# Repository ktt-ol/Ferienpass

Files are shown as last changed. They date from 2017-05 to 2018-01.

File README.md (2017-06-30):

# Ferienpass

## Submodules
We use the [kicad-ESP8266][kicadESP8266Lib] Libary form [jdunmire][ESP8266LibAuthor].

To clone the whole Repository including the submodules simpy use the `--recusive` Option or run the Commands `git submodule init && git submodule update` inside this repository adter cloning.

[kicadESP8266Lib]: https://github.com/jdunmire/kicad-ESP8266
[ESP8266LibAuthor]: https://github.com/jdunmire

## Arduino Library
Install the following librarys via the Arduino IDE:
- Adafruit BME280 Library
- Adafruit GFX LIbrary
- Adafruit NeoPixel
- Adafruit Unified Sensor
- ACROBOTIC SSD1306

Modify three lib-files (first two for I2C):
- Adafruit_BME280.h: Line 32: Change `BME280_ADDRESS` from `0x77` to `0x76`
- Adafruit_BME280.cpp: Line 50: Change `Wire.begin();` to `Wire.begin(5, 4); // Pin D1, D2 of ESP`
- Adafruit_SSD1306.h: Line 73/74: use line 73 `#define SSD1306_128_64`  instead of line 74 `#define SSD1306_128_32`

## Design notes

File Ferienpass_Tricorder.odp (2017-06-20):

## Ferienpass

Multifunktionssensor bauen

## Vorstellungsrunde

## Spaceführung

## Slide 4

Löten lernen

## Löten lernen

- Lötkolben und Lötzinn
- Fachbegriffe
- Bauteile
  - Typen
  - Hinweise
- Richtig löten

## Lötkolben und Lötzinn

- Der Lötkolben wird sehr heiß (ca. 200°C)
- Das Lötzinn besteht aus Flussmittel, Zinn und Blei
- Nach dem Löten unbedingt die Hände waschen, da das Lötzinn gesundheitsschädlich ist!

## Fachbegriffe: U = R × I

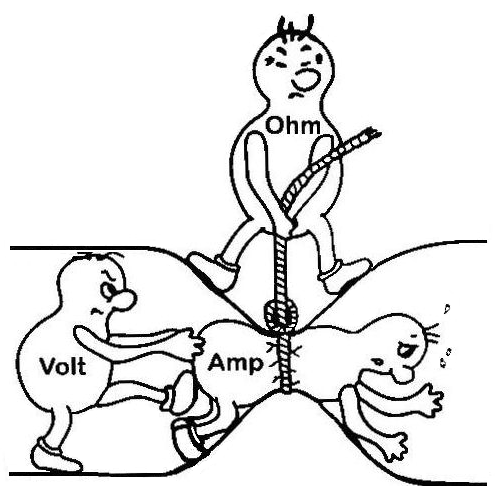
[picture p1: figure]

## Bauteile - Widerstand

- Zeichen: R
- Polung: Keine
- Einheit: Ohm
- Anhand von Farbringen erkennbar
- Beispiel

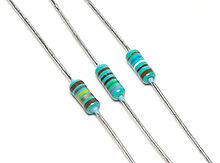
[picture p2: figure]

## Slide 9

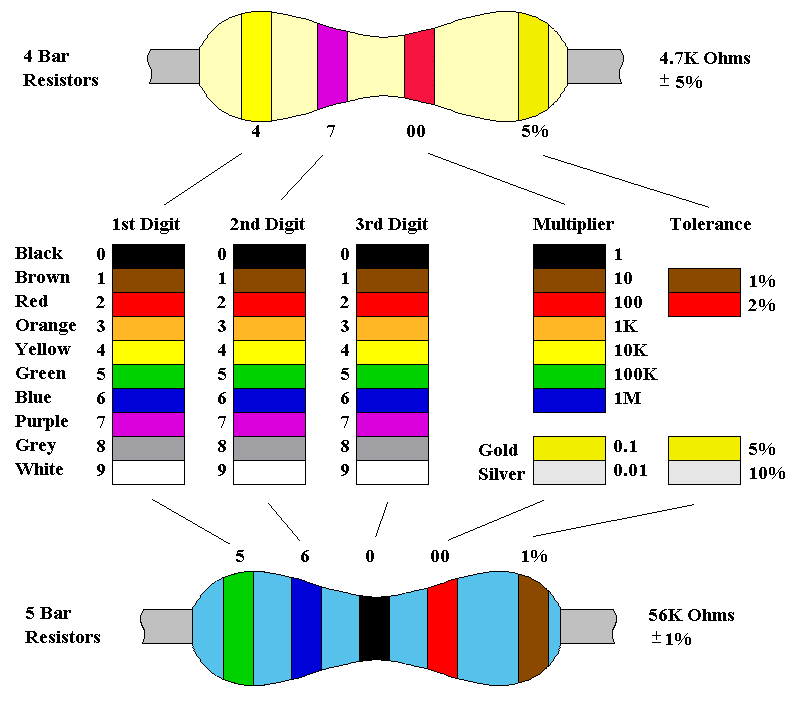
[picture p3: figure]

## Bauteile - Kondensator

- Zeichen: C
- Polung: Ja
- Einheit: Farad (F)
- Kondensator:
- Energiespeicher
- Spannungsausfall überbrücken

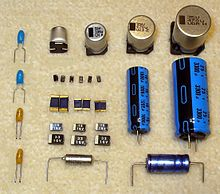
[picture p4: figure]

## Bauteile - Sensor

BME280

- Temperatur
- Luftdruck
- Luftfeuchtigkeit

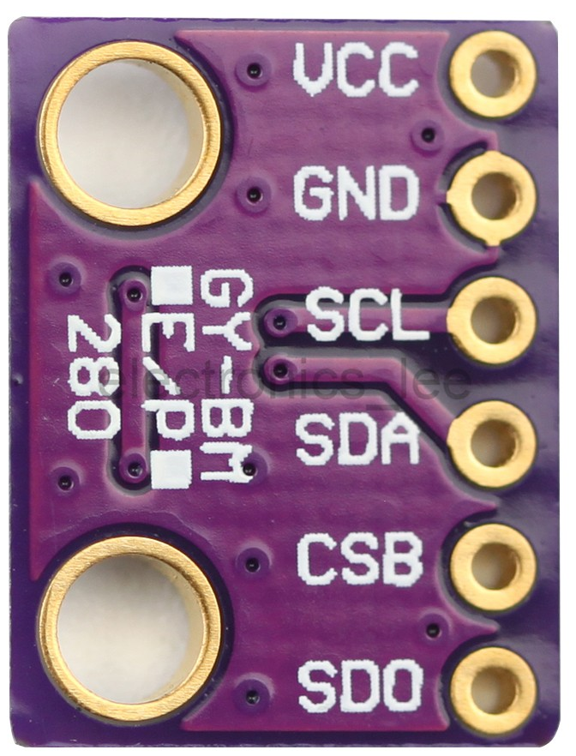
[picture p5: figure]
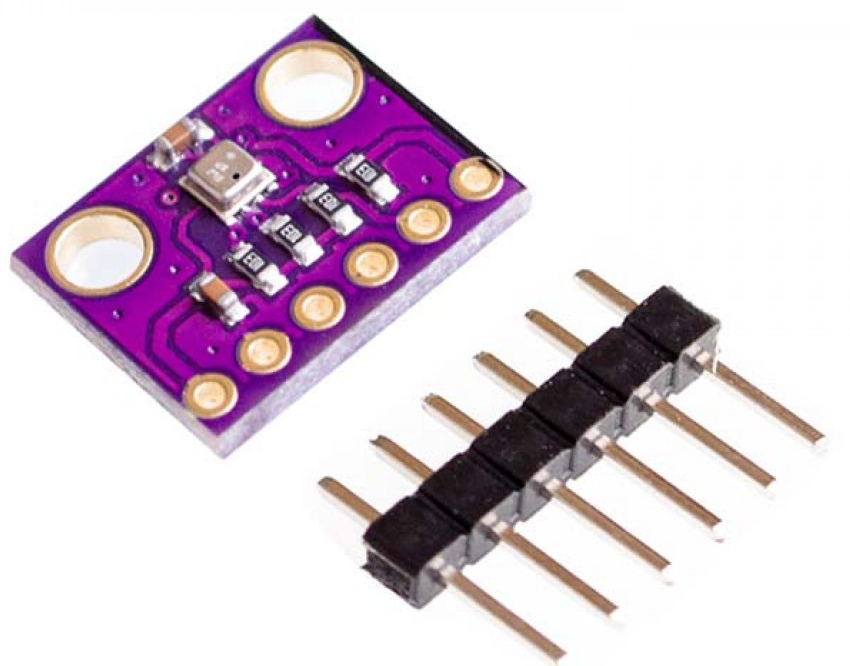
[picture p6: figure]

## Bauteile – RGB LED

- RotGrünBlau Leuchtdiode
- Formelzeichen: D (Diode)
- Polung: Ja
- Anode (+), Kathode (-)

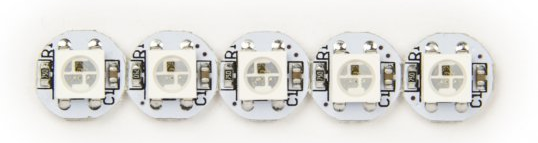
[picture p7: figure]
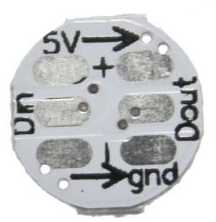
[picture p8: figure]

## Bauteile – Display

- OLED Display 0,96“
- I2C Anschluss
- TODO: Foto der BME Anzeige!

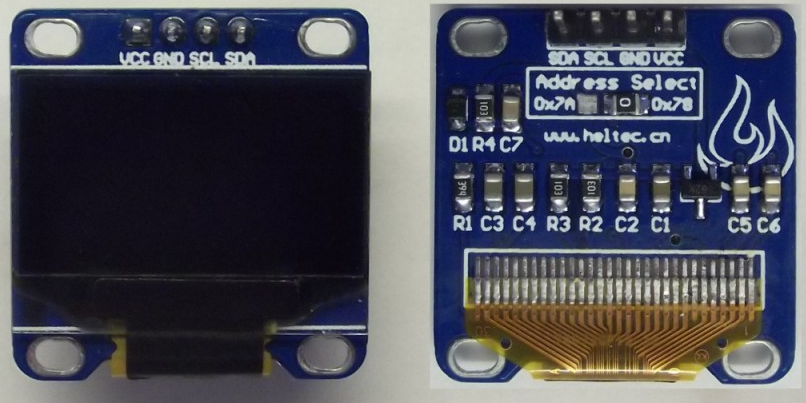
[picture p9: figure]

## Bauteile - ESP

- NodeMCU12E (ESP8266)
- Logischer Baustein
- System on a Chip (SoC)
- Kleiner Computer
- Programmierbar
- “Verhalten” des Trikorders
- Sensor: WLAN

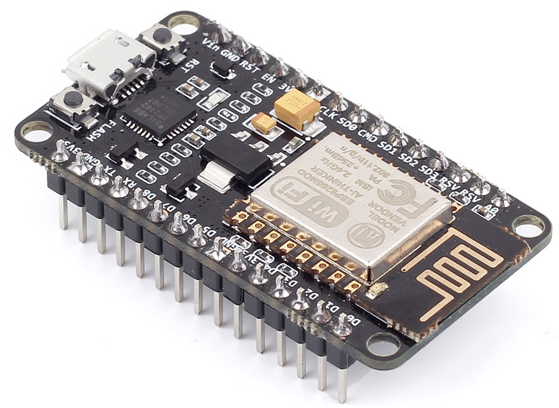
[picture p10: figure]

## Bauteile - Sonstige

- Sensor: Mikrofon
- Summer
- Button
- Stiftleisten
- Batteriepack
- Schalter

## Richtig löten

- Lötstelle zuerst erhitzen und dann erst das Lötzinn an die Lötstelle halten
- Beim Abknipsen der Beine diese festhalten
  (das geht sonst ins Auge)
- Wenn die Lötspitze verdreckt ist diese vorsichtig am
  Schwamm abwischen

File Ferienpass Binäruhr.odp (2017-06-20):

## Ferienpass

Binäruhr Bauen

## Vorstellungsrunde

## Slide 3

Das Binärsystem

## 101010

1 0 1 0 1 0

32 16 8 4 2 1

32 + 8 + 2 = 42

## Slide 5

Löten Lernen

## Löten lernen

- Lötkolben und Lötzinn
- Fachbegriffe
- Bauteile
  - Typen
  - Hinweise
- Richtig Löten

## Lötkolben und Lötzinn

- Der Lötkolben wir sehr Heiß (ca 200°C)
- Das Lotzinn besteht aus Flussmittel, Zinn und Blei
- Nach dem Löten unbedingt die Hände Waschen, da das Lötzinn gesundheitsschädlich ist!

## Fachbegriffe: U = R × I


## Bauteile - Widerstand

Zeichen: R

Polung: Keine

Einheit: Ohm

Anhand von Farbringen erkennbar

Beispiel


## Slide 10


## Bauteile - Kondensator

Zeichen: C

Polung: Ja

Einheit: Farad (F)

Kondensator:

Energiespeicher

Spannungsausfall
überbrücken


## Bauteile - Quarz

Zeichen: X

Polung: Nein

Einheit: Herz

Gibt Takt durch Schwingung vor

(Clock)

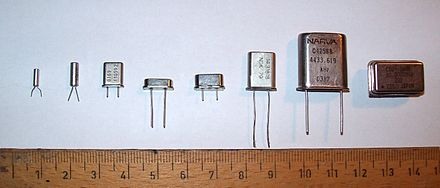
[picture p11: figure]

## Bauteile - Transistor

Zeichen: Q

Polung: Ja, 3 Pole

Fungiert als Schalter

Emitter, Collector, Basis

Verstärkung von Strömen

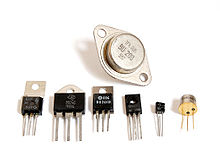
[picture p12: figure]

## Bauteile - LED

Leuchtdiode

Formelzeichen: D (Diode)

Polung: Ja

Anode (+), Kathode (-)

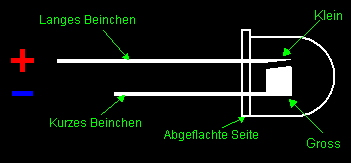
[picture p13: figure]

## Bauteile - IC

Integrated Circuit (Integrierter Schaltkreis)

Logische Bausteine

Kleiner Computer

Programmierbar

“Verhalten” der Uhr

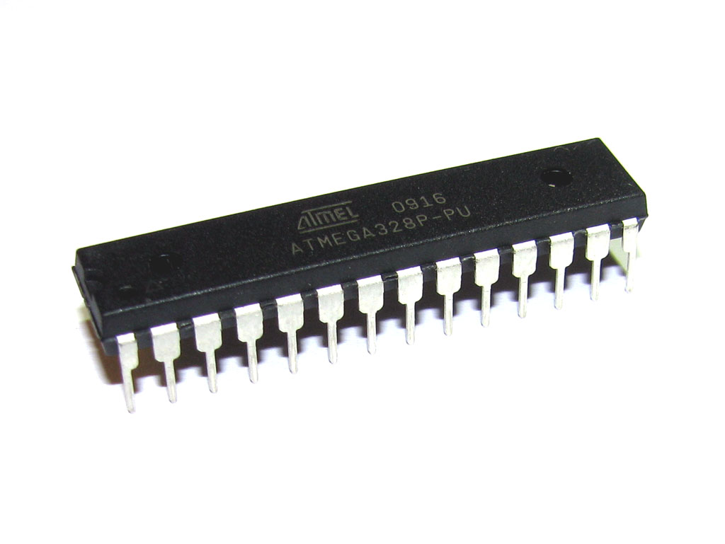
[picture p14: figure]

## Bauteile - Sonstige

Lichtsensor

USB Buchse

RTC

Taster

Stiftleisten

## Richtig löten

Lötstelle zuerst erhitzen und dann erst das Lötzinn an die Lötstelle halten

Beim Abknipsen der Beine diese festhalten (das geht sonst ins Auge)

Wenn die Lötspitze verdreckt ist diese vorsichtig am schwamm abwischen

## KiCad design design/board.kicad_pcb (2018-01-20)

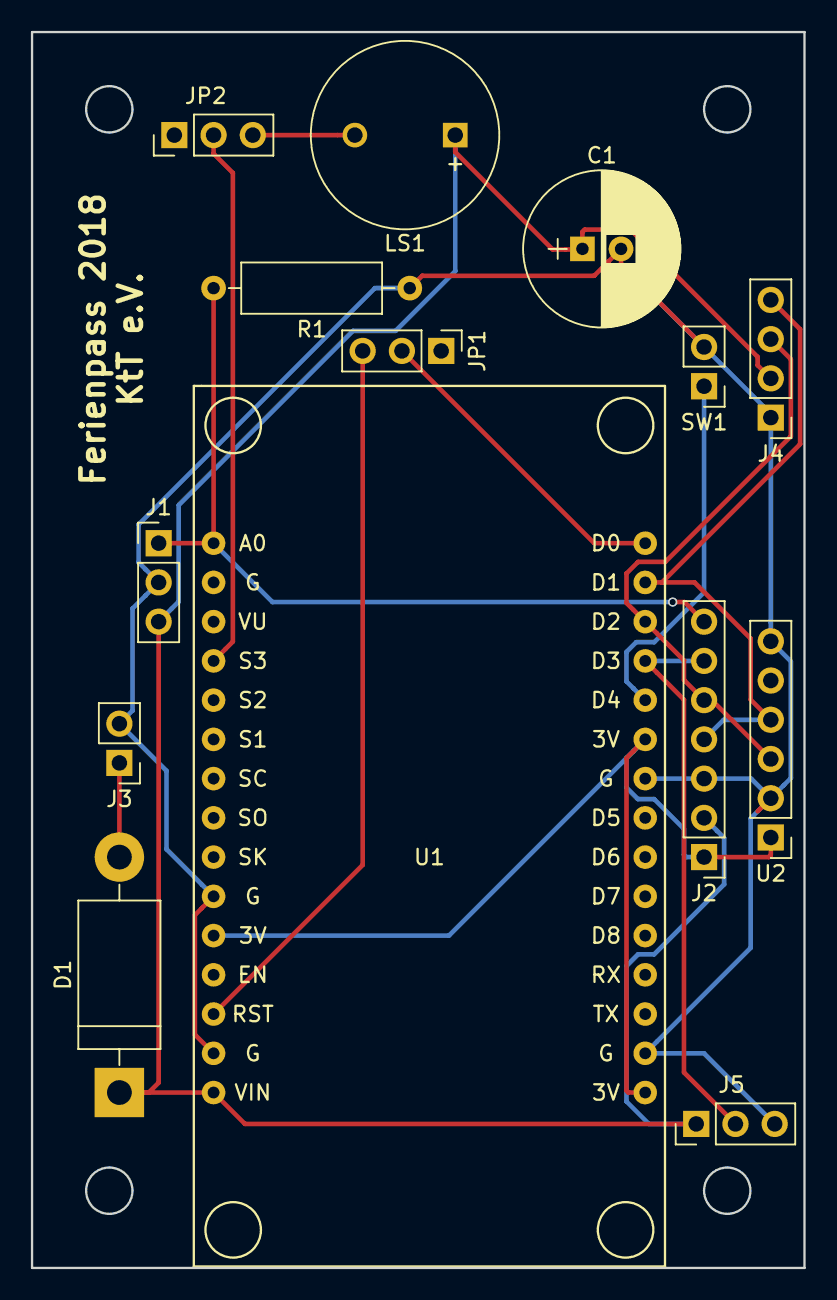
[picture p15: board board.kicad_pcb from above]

Board: 2 copper layers, 50.0 x 80.0 mm, 14 parts (0 on the bottom side), 13 nets.

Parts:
C1: 2200µF; CP_Radial_D10.0mm_P2.50mm
D1: D; D_DO-201AD_P15.24mm_Horizontal
J1: Mic; Socket_Strip_Straight_1x03_Pitch2.54mm
J2: DEBUG_CONN; Socket_Strip_Straight_1x07_Pitch2.54mm
J3: PWR_CONN; Pin_Header_Straight_1x02_Pitch2.54mm
J4: 0.97" OLED; Socket_Strip_Straight_1x04_Pitch2.54mm
J5: WS2812b; Socket_Strip_Straight_1x03_Pitch2.54mm
JP1: DSLEEP_JUMP; Pin_Header_Straight_1x03_Pitch2.54mm
JP2: BEEPER_JUMP; Pin_Header_Straight_1x03_Pitch2.54mm
LS1: Speaker; MagneticBuzzer_ProSignal_ABT-410-RC
R1: 10K; R_Axial_DIN0309_L9.0mm_D3.2mm_P12.70mm_Horizontal
SW1: SW_Push; Socket_Strip_Straight_1x02_Pitch2.54mm
U1: NodeMCU1.0(ESP-12E); NodeMCU1.0(12-E)
U2: BME280; Socket_Strip_Straight_1x06_Pitch2.54mm

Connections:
+3V3: J2.1, U1.11, U1.16, U1.25, U2.1
D0: JP1.2, U1.30
GND: C1.2, J1.2, J2.3, J3.2, J4.1, J5.3, R1.1, SW1.2, U1.10, U1.14, U1.17, U1.24, U2.2, U2.6
MIC: J1.1, J2.7, R1.2, U1.1
unnamed: D1.2, J3.1
unnamed: JP1.3, U1.13
unnamed: JP2.3, LS1.2
unnamed: SW1.1, U1.26
SCL: J2.5, J4.3, U1.28, U2.3
SD3: JP2.2, U1.4
SDA: J2.4, J4.4, U1.29, U2.4
VCC: C1.1, D1.1, J1.3, J2.2, J4.2, J5.1, LS1.1, U1.15
WS2812b: J2.6, J5.2, U1.27

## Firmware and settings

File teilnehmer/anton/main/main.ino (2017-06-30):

#include <Wire.h>
#include <SPI.h>
#include <Adafruit_Sensor.h>
#include <Adafruit_BME280.h> // Adafruit_BME280_Library (1.0.5) [modified for I2C!], Adafruit_Unified_Sensor (1.0.2)
#include "sensors.h"
#include "ESP8266WiFi.h"
#include <Adafruit_NeoPixel.h> // LEDs
#include <ACROBOTIC_SSD1306.h> // Display

#define BUTTONPIN      D4
#define LEDPIN         D3 
#define BEEPPIN        10 // SD3
#define NUMPIXELS      25  // Number of NeoPixels/LEDs
#define DISPLAYADDR 0x78
#define DISPLAYROWS 8

// LEDs
Adafruit_NeoPixel pixels = Adafruit_NeoPixel(NUMPIXELS, LEDPIN, NEO_GRB + NEO_KHZ800);

// BME
Adafruit_BME280 bme; // I2C  // D1 = SDA, D2 = SCL

//int LDR_Pin = A0;
int buttonState = 0;
int mode = 0;
Sensors sensor(bme);

// Values for microphone
const int THRESHOLD = 20;
const int VAL_MEAN = 507;
// trigger characteristics
const int CLAPS_TO_TRIGGER = 2; // number of claps
const int DEBOUNCE_TIME = 150; // ms to ignore double-clapping
const int SILENCE_T = 40; // ms between claps, otherwise reset
const int MELODY_INTERVAL = 800; // ms max time for the claps
const int PAUSE_TIME = 2000; // wait after switch, or noise
// pin-layout
const int analogPin = 0;
//const int OUTPUT_PIN = 13;    
int output_state = LOW;
uint32_t pause_t = 0;
uint32_t debounce_t = 0;
uint32_t start_time = 0; // timestamp of first clap-start
uint8_t claps = 0;
int sensorVal = 0;
int amp = 0; 
// End values for microphone
float minTemp = 80;
float maxTemp = -20;

void setup() {
	Serial.begin(9600);
  Serial.println("Starting ESP...");
  pixels.begin(); // This initializes the NeoPixel library für LEDs
  
  // Display
  oled.init();                      // Initialze SSD1306 OLED display
  oled.clearDisplay();              // Clear screen  
  //oled.drawBitmap(MAINFRAME, 1024); // TODO: 1024px Mainframelogo
  oled.setTextXY(0,0); 
       
  pinMode(BUTTONPIN, INPUT);        
  pinMode(LEDPIN, OUTPUT);  
  pinMode(BEEPPIN, OUTPUT);  

  attachInterrupt(digitalPinToInterrupt(BUTTONPIN), isr, FALLING);
  beep(1, 128);
  delay(20);
  testLeds();
  delay(40);
}

void isr() {
  //beep(4, 128);
  Serial.println("INTERURPT!");
  oled.clearDisplay();
  mode = ++mode % 3;
}

void ampLEDs(int amp)  {
  amp = amp / 20;
  if(amp > 23) {
    amp = 23;
  }
    
  for(int i=0;i<amp;i++) {
    pixels.setPixelColor(i, pixels.Color(i*10,255,0));        
    pixels.setBrightness(10); // Helligkeit
    pixels.show(); // This sends the updated pixel color to the hardware.
    delay(10);
  } 
    for(int i=amp;i<NUMPIXELS;i++) {
    pixels.setPixelColor(i, pixels.Color(0,0,0));        
    pixels.setBrightness(10); // Helligkeit
    pixels.show(); // This sends the updated pixel color to the hardware.
    delay(10);
  } 
}

void clearLEDs() {
    for(int i=0;i<NUMPIXELS;i++) {
      pixels.setPixelColor(i, pixels.Color(0,0,0)); 
      pixels.setBrightness(10);
      pixels.show();
      delay(10); 
  }
}

void testLeds() {
  for(int i=0;i<NUMPIXELS;i++) {
    // Helligkeit
    pixels.setPixelColor(i, pixels.Color(0,0,150)); // RGB
    pixels.setBrightness(10);
    pixels.show(); // This sends the updated pixel color to the hardware.
    delay(100);
  }
  delay(500);
  for(int i=0;i<NUMPIXELS;i++) {
    pixels.setPixelColor(i, pixels.Color(0,0,0)); 
    pixels.setBrightness(10);
    pixels.show();
    delay(100); 
  }
}

void showBME() {
  float currentTemp = sensor.getTemperature();
  if(currentTemp<minTemp){
    minTemp = currentTemp;
  }else if (currentTemp>maxTemp){
    maxTemp = currentTemp;
  }
  float currentHum = sensor.getHumidity();
  float currentPres = sensor.getPressure();
    oled.setTextXY(0,0);  
    oled.putString("= Umweltwerte =");
    
    oled.setTextXY(2,0);
    oled.putString("T: ");
    oled.putString((String) currentTemp);
    oled.putString(" C");

    oled.setTextXY(3,0);
    oled.putString("P: ");
    oled.putString((String) currentPres);
    oled.putString(" hPa");

    oled.setTextXY(4,0);
    oled.putString("H: ");
    oled.putString((String) currentHum);
    oled.putString(" %");
   
    float TempLED = (currentTemp/8)+1;
    oled.setTextXY(5,0);
    oled.putString("TLED: ");
    oled.putString((String) TempLED);

    float PreLED = (currentPres-1000)/25+4;
    oled.setTextXY(6,0);
    oled.putString("HLED: ");
    oled.putString((String) PreLED);
    for(int i=16;i<NUMPIXELS;i++) {
      // Helligkeit
      if(i<(16+TempLED)){
      pixels.setPixelColor(i, pixels.Color(10*(i-16),0,6*(16-(i-16)))); // RGB
      pixels.setBrightness(20);
      }else{
      pixels.setPixelColor(i, pixels.Color(0,0,0)); // RGB
      pixels.setBrightness(20);
      }
      pixels.show(); // This sends the updated pixel color to the hardware.
      delay(50);
    }


    for(int i=15;i>7;i--) {
      // Helligkeit
      if(i>=15-PreLED){
        pixels.setPixelColor(i, pixels.Color(0,255,0)); // RGB
        pixels.setBrightness(20);
        pixels.show(); // This sends the updated pixel color to the hardware.
        delay(50);
      }
    }
     
      // Helligkeit
      // 30 - 70%
        if(currentHum >= 30.0) {
          int maxLED = (int) (currentHum-25.0)/5.0;
          if(maxLED > 8) {
            maxLED = 8;
          }
          for(int i=0;i<maxLED;i++) {
            pixels.setPixelColor(i, pixels.Color(255,255,0)); // RGB
            pixels.setBrightness(20);
            pixels.show(); // This sends the updated pixel color to the hardware.
            delay(50);
          }
          for(int i=maxLED;i<8;i++) {
            pixels.setPixelColor(i, pixels.Color(0,0,0)); // RGB
            pixels.setBrightness(20);
            pixels.show(); // This sends the updated pixel color to the hardware.
            delay(50);
          }
        }
        else {
          for(int i=0;i<8;i++) {
            pixels.setPixelColor(i, pixels.Color(0,0,0)); // RGB
            pixels.setBrightness(20);
            pixels.show(); // This sends the updated pixel color to the hardware.
            delay(50);
          }
        }
    
    // Serial
		Serial.print("Temperature = ");
		Serial.print(sensor.getTemperature());
		Serial.println(" *C");

		Serial.print("Pressure = ");
		Serial.print(sensor.getPressure());
		Serial.println(" hPa");

		Serial.print("Humidity = ");
		Serial.print(sensor.getHumidity());
		Serial.println(" %");
   
		Serial.println();   
}

void beep(int count, int frequency) {
   for(int i=0; i<count; i++) {
    analogWrite(BEEPPIN, frequency);
    delay(1000);
    analogWrite(BEEPPIN, 0);
    delay(1000);
   }
}

void clearRow(char row) {
  for(char column=0; column<16; column++) {
    oled.setTextXY(row,column); 
    oled.putString(" ");    
  }
}
 
 void clearMultipleRows(char firstRow, char lastRow) {
  for(char row=firstRow; row<lastRow; row++) {
    for(char column=0; column<16; column++) {
      oled.setTextXY(row,column); 
      oled.putString(" ");    
    }
  }
}

void showWlans() {
   // WLAN 
  int n = WiFi.scanNetworks();

  // Clear WLANs from last scan
  if(n < DISPLAYROWS-1) {
    clearMultipleRows(n+1, DISPLAYROWS);
  }
  
  int row = 1;
  for (int i=0; i<n; ++i) {
    if(mode != 1){
      oled.clearDisplay(); 
      break;
    }
    //oled.clearDisplay();
    oled.setTextXY(0,0);
    oled.putString("Found "+ (String)n +" WLANs!");

    // More WLANs than display rows
    if(i > 0 && i % (DISPLAYROWS-1) == 0) { 
      row  = 1;
      delay(5000);
    }
    clearRow(row);
    oled.setTextXY(row,0);
    //oled.putString((String) i + ")");
    oled.putString((WiFi.encryptionType(i) == ENC_TYPE_NONE)?" ":"*");
    oled.putString((String) WiFi.SSID(i));
    oled.putString("\n");    
    row++;
    delay(20);    
  }
}


void micReset() {
  // time has expired
  start_time = 0;
  claps = 0;
  debounce_t = 0;
  Serial.println(F("reset"));
}

void startMic() {
  sensorVal = analogRead(analogPin);
  amp = abs(sensorVal-VAL_MEAN);
  ampLEDs(amp);

  // Serial.print(F("sensed: ")); Serial.println(sensorVal);
  // Serial.print(F("amp: ")); Serial.println(amp);

  // at the end of an interval check the number of claps
  if (millis()-start_time > MELODY_INTERVAL & claps != 0) {
    if (claps == CLAPS_TO_TRIGGER & millis()-pause_t > PAUSE_TIME) {
      output_state = !output_state;
      pause_t = millis();
      //digitalWrite(OUTPUT_PIN,output_state);
      Serial.print(F("Triggered "));
      Serial.println(output_state);
    }
    if (claps>CLAPS_TO_TRIGGER) { Serial.print(F("- too many")); }
    micReset();
  }

  // noise/clap detected
  if (amp > THRESHOLD &\
      millis()-debounce_t > DEBOUNCE_TIME &\
      millis()-pause_t > PAUSE_TIME) {
    // there has to be silence between claps
    if (millis()-debounce_t < SILENCE_T+DEBOUNCE_TIME) {
      claps = 0;
      debounce_t = millis();
      Serial.print(F("reset - silence interrupted"));
      Serial.print(F(" amp "));Serial.println(amp);
      clearRow(2);
      oled.setTextXY(2,0);
      oled.putString("amp: "+(String)amp);
    } else {
      claps++;
      debounce_t = millis();
      Serial.print(F("claps "));Serial.print(claps);
      Serial.print(F(" amp "));Serial.println(amp);
      clearRow(2);
      oled.setTextXY(2,0);
      oled.putString("amp: "+(String)amp);
      if (claps == 1) { start_time = debounce_t; }
    }
  }
  delay(1);
}

void loop() {
  /* LDR  for next release
  float ldr = sensor.getBrightness(LDR_Pin);
  Serial.print("LDR-Brightness: "+ (String)ldr +" !\n");
  */
  
  Serial.println("Buttonstate: " + (String)buttonState);
  Serial.println("Mode: " + (String)mode);

  
  switch(mode) {
    case 0:
      showBME();  
      //testLeds();       
      break;
    case 1:      
      showWlans();
      clearLEDs();
      break;
    case 2:
      startMic();
      break;
    default:
      showBME(); 
      break;
  }
  
  //beep(4, 128);
	
	delay(500);        
}

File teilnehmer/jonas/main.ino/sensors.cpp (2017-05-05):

#include "sensors.h"

Sensors::Sensors(Adafruit_BME280 bme) {
  Serial.println("Sensor Test");
  if (!bme.begin())  {
    Serial.print("No BME280 detected ... Check your wiring or I2C ADDR!\n");
    while(1);
  }
   else {
    Serial.println("BME280 ready.\n");
  }
	this->bme = bme;
	this->pressure = 0.0F;
	this->temperature = 0.0F;
	this->humidity = 0.0F;
	this->brightness = 0.0F;
}

float Sensors::getPressure() {
 	this->pressure = this->bme.readPressure() / 100.0F;
 	return this->pressure;
 }	

float Sensors::getTemperature() {
	this->temperature = bme.readTemperature();
	return this->temperature;
}

float Sensors::getHumidity() {
	this->humidity = bme.readHumidity();
	return this->humidity;
}

float Sensors::getBrightness(int LDR_Pin) {
	this->brightness = analogRead(LDR_Pin);
	return this->brightness;
}

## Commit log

2017-02-18 initial sensor framework for esp8266
2017-02-18 sensor class
2017-02-18 test programm for bme280 sensor
2017-04-08 design and main testprogramm
    [board.kicad_pcb, board.sch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]
2017-04-15 ws2812b Anschluss auf dem Schaltplan hinzugefügt
    [board.sch]
2017-04-23 ESP2866 Libary for KiCAD is now a Submodule
2017-05-05 Schaltplan aktualisiert und erweitert
    [board.sch]
2017-05-05 fixed bme sensor init, add led and display example
    [main.ino, sensors.cpp]
2017-05-06 show wlans and sensor values on oled display
2017-05-12 beeper, fixed wlans on display
    [main.ino]
2017-05-12 modified and refresched
    [board.sch]
2017-05-16 finalizing PCB Layout
    [board.kicad_pcb, board.sch]
2017-05-18 added some Text on Silkscreen and some holes
    [board.kicad_pcb]
2017-05-19 finalizied board layout
    [board.kicad_pcb]
2017-06-06 correction of the Nodemcu Footprint
    [board-B.Cu.gbr, board-B.SilkS.gbr, board-F.SilkS.gbr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]
2017-06-20 praesentation sensor
2017-06-20 button interrupt fixed
2017-06-24 led brightness
2017-06-26 led number and presi
2018-01-20 improved PCB-Layout for next Year
    [board.kicad_pcb]
